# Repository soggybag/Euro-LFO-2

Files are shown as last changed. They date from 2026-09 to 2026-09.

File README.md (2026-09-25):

# Euro-LFO-2

Claude Conversation about the LFO Math

Here's the whole thing in one place, cleaned up.

## The circuit

```
        R6 10K        SHAPE 500K        D1/D2         RATE 100K
U1B(-) ──/\/\──── wiper ──/\/\──┬──── steering ────── wiper
  │                             │      diodes           │  pin1 = square (U1A out)
 C1 47n (to U1B out)                                     │  pin3 = GND via R4 4K7
                                                    
U1B: integrator   (+in = GND, C1 from out→in, out = triangle)
U1A: Schmitt trig  (-in = GND, +in from R1 150K [own out] and R5 100K [triangle])
     out = square, ±V_sat
```

## Step 1 — Schmitt thresholds set the triangle amplitude

U1A's + input, no current into the pin:

```
V+ = (V_tri·R1 + V_sq·R5) / (R1 + R5)
```

Trips when `V+ = 0`:

```
V_tri,trip = −V_sq · (R5/R1)
```

So the triangle bounces between `±V_sat·(R5/R1)`, giving a peak-to-peak swing:

```
ΔV_pp = 2·V_sat·(R5/R1) = 2·V_sat·(100K/150K) = 1.33·V_sat  ≈ 14 V pp  (±7 V)
```

## Step 2 — Integrator ramp rate

Summing node is a virtual ground, so the timing current is set entirely by the drive voltage and the series resistance:

```
slope = |dV_tri/dt| = V_drive / (R_t · C1)
```

`V_drive` = RATE wiper voltage minus one diode drop; `R_t` = series resistance for that half-cycle.

## Step 3 — Period

Each ramp traverses the **full** pp swing, and the two halves use the two halves of SHAPE (`R_a + R_b = 500K`) with R6 and the RATE source resistance `R_th` in both:

```
T = t_up + t_down
  = 2·(R5/R1)·(V_sat/V_drive)·C1·[ (R6 + R_a + R_th) + (R6 + R_b + R_th) ]
```

```
┌────────────────────────────────────────────────────────────────┐
│  T = 2·(R5/R1)·C1·( 2·R6 + R_SHAPE + 2·R_th ) · V_sat/(V_th−V_f) │
└────────────────────────────────────────────────────────────────┘
```

Key point: **R6 and R_th count twice** (in the path on both ramps); **SHAPE counts once** (the wiper splits it, halves sum to 500 K). That's why SHAPE changes symmetry/PWM but not frequency.

## Idealized form (RATE max, ignore diode)

`V_th → V_sat`, `R_th → 0`, and **V_sat cancels**:

```
        R1                    1
f  ≈  ────── · ──────────────────────────────
        R5       2 · C1 · (2·R6 + R_SHAPE)
```

## Numbers

```
R1/R5 = 1.5
2·C1·(2·R6 + R_SHAPE) = 2·(47 nF)·(20K + 500K) = 0.0489

f_max ≈ 1.5 / 0.0489 ≈ 31 Hz     (T ≈ 33 ms)
```

As RATE turns down, `V_th` falls and stretches the period:

| RATE wiper | V_th | f (approx) |
|---|---|---|
| full up | V_sat | ~30 Hz |
| middle | ~0.5·V_sat | ~14 Hz |
| near bottom | ~0.045·V_sat ≈ 0.47 V | crawls / stalls (below the ~0.5 V diode drop) |

**Practical range ≈ 0.3 Hz to ~30 Hz.**

## Notes

- **V_sat** ≈ ±10.5 V (TL074 stops ~1.5 V short of the rails). It drops out of the ideal formula — bigger swing = taller triangle *and* faster ramp, cancels.
- **Op-amp is now an LM324DT** (JLCPCB basic part C71035, pin-compatible with the TL074). Its swing is asymmetric — about +10.5 V but down to within a few hundred mV of −12 V — so the Schmitt thresholds are uneven: expect a ~0.5 V DC offset on the triangle and SHAPE's 50 % point shifted slightly off centre. Its ~0.4 V/µs slew gives ~50 µs square-wave edges, irrelevant at LFO rates. A TL074 still drops straight in if you want the symmetric JFET behaviour.
- Comparator propagation delay with the LM324 is a few µs vs a 33 ms period → still negligible.
- **V_f** ≈ 0.4–0.5 V steering-diode drop. It does *not* scale with V_sat, so it's what makes the low end nonlinear and adds mild temp drift (−2 mV/°C).
- **To lower the whole range**, scale **C1** up (470 n → ~0.1–3 Hz; 1 µF → ~1.4 Hz max). Don't retune with R5/R1 — that moves amplitude and frequency together.
- **C1 dielectric:** X7R drifts a few % — fine for an LFO. C0G only if you want the rate rock-stable.

Close, but the RATE knob isn't a series resistance you can add — it's a **voltage divider** on the drive (square wave → wiper → GND through R4). So it *multiplies* the rate rather than adding to the timing resistance.

## Ballpark model

**Fast end (RATE maxed)** — the idealized formula as-is:

```
        R1                1                1.5
f_max ≈ ── · ───────────────────────── ≈ ───────────── ≈ 30 Hz
        R5    2·C1·(2·R6 + R_SHAPE)      2·47n·520K
```

**Anywhere else** — scale by the knob:

```
f ≈ f_max · (V_th / V_sat) ≈ f_max · (fraction of knob rotation)
```

roughly linear for a linear-taper pot.

**Slow end (RATE at minimum)** — the drive collapses to the R4 divider:

```
                R4              4.7K
f_min ≈ f_max · ────────── ≈ 30·────── ≈ 1.4 Hz
                R_RATE+R4        104.7K
```

and the ~0.45 V diode drop eats the last sliver, so it actually **stalls at the end stop** — call the usable floor ~1 Hz.

## So

**~1 Hz to ~30 Hz, ~15 Hz at noon.**

## Why "+100K after R_SHAPE" doesn't give the min

The RATE pot's *resistance* contribution (its Thévenin source R looking back into the wiper) only swings from 0 to about **25K** — parallel combination of its two halves — and even at max that changes `f` by ~5%. The 20:1 rate span is entirely the *voltage* division, which is a multiplier, not a term you add to the ohms.

If you want the classic slow-LFO window, scale **C1**: 470 n → ~0.1–3 Hz, 1 µF → ~0.05–1.4 Hz.

It depends on what you want it to modulate, but here are the anchor points:

| Use | Rate | Period |
|---|---|---|
| Slow evolving pad / drone movement | 0.01–0.1 Hz | 10–100 s |
| Once per bar (120 BPM, 4/4) | 0.5 Hz | 2 s |
| Once per beat (120 BPM) | 2 Hz | 0.5 s |
| Rhythmic "wobble" | 1–8 Hz | — |
| Vibrato / tremolo | 4–8 Hz | — |
| Buzzy / edge-of-audio modulation | 20–30 Hz | — |
| Audio-rate (through-zero FM, AM, LFO-as-oscillator) | 30 Hz–2 kHz | — |

## The all-rounder target

A standalone modulation LFO wants roughly **0.05 Hz (≈20 s) to ~20 Hz** — that covers "slow filter sweep" up through "vibrato." The catch is that's a ~400:1 span, and a single knob over that range feels terrible with a linear taper (everything useful is crammed into the last few degrees). So real LFOs do one of:

- **Tapered pot** — reverse-log / "C" taper on RATE so the slow-to-medium zone gets most of the rotation.
- **Range switch** — a 2- or 3-position switch that swaps the timing cap, e.g. slow / med / fast.
- Both.

Extending the top past ~30 Hz into audio rate is a nice bonus but a separate design goal — this TL074 + diode-shaper topology isn't built for clean audio-rate output, so I'd not chase it here.

## For your circuit

Your span ratio is locked at about `(R_RATE + R4)/R4 ≈ 22:1` by the RATE divider. C1 just slides that 22:1 window up or down:

| C1 | Range | Character |
|---|---|---|
| 47 nF (now) | ~1.4–30 Hz | fast LFO — no slow sweeps |
| **100 nF** | **~0.7–14 Hz** | good general-purpose single range |
| 220 nF | ~0.3–6 Hz | slow/medium |
| 1 µF | ~0.06–1.4 Hz | slow-only |

My suggestion: **C1 = 100 nF** for a better single-range LFO, plus a **SPDT range switch** paralleling a larger cap (say +2.2 µF) to drop into a slow mode (~0.03–0.6 Hz) when you want it. And swap RATE to a reverse-log pot.

Don't try to widen the 22:1 span much by shrinking R4 — the steering diodes need the wiper voltage to stay above ~1 V to keep oscillating, so the bottom of the knob just goes mushy and stalls rather than getting genuinely slow. Sliding the window with C1 (or switching it) is the reliable lever.

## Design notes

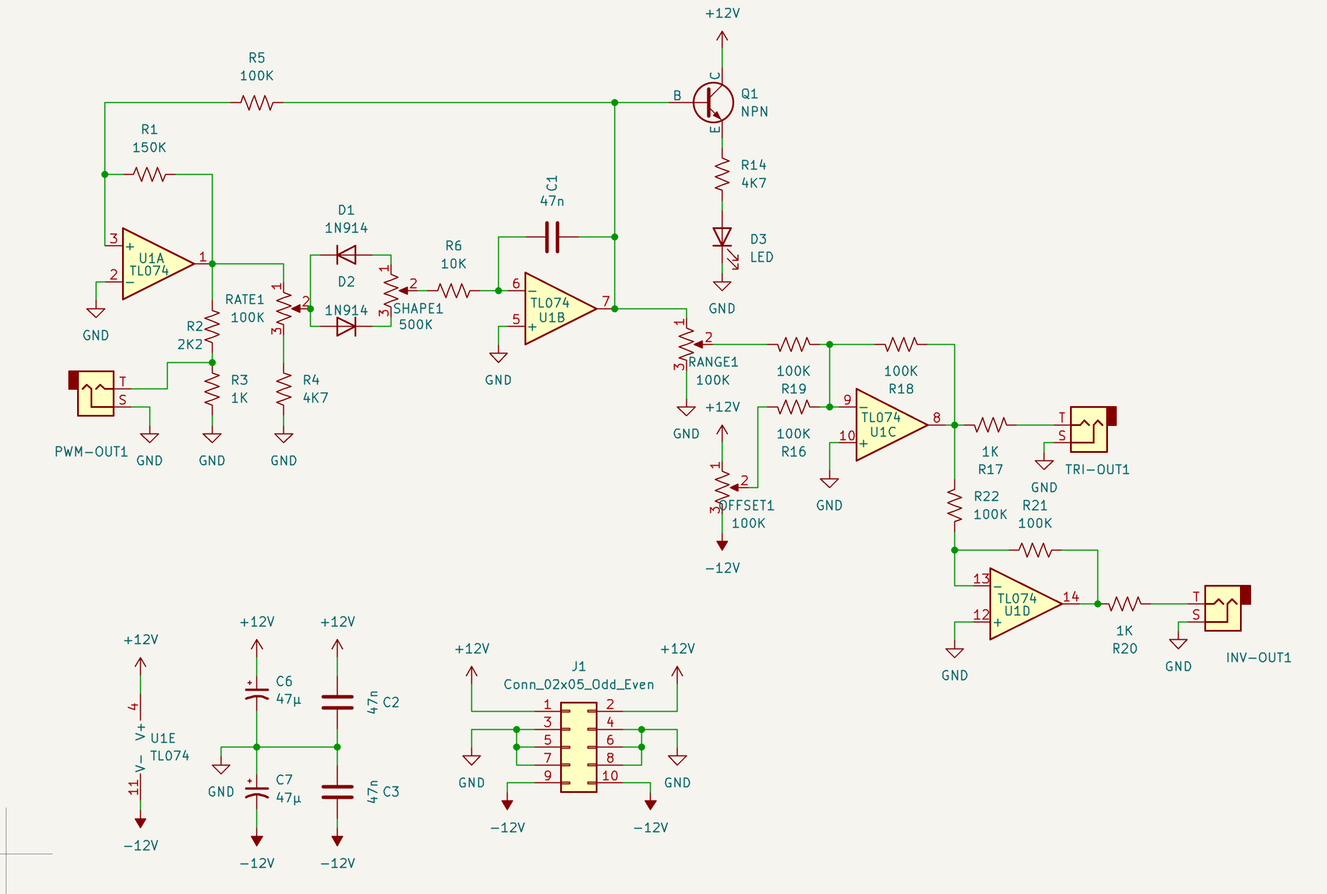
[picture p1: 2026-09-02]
Screenshot 2026-08-28 at 5.44.02 PM.png

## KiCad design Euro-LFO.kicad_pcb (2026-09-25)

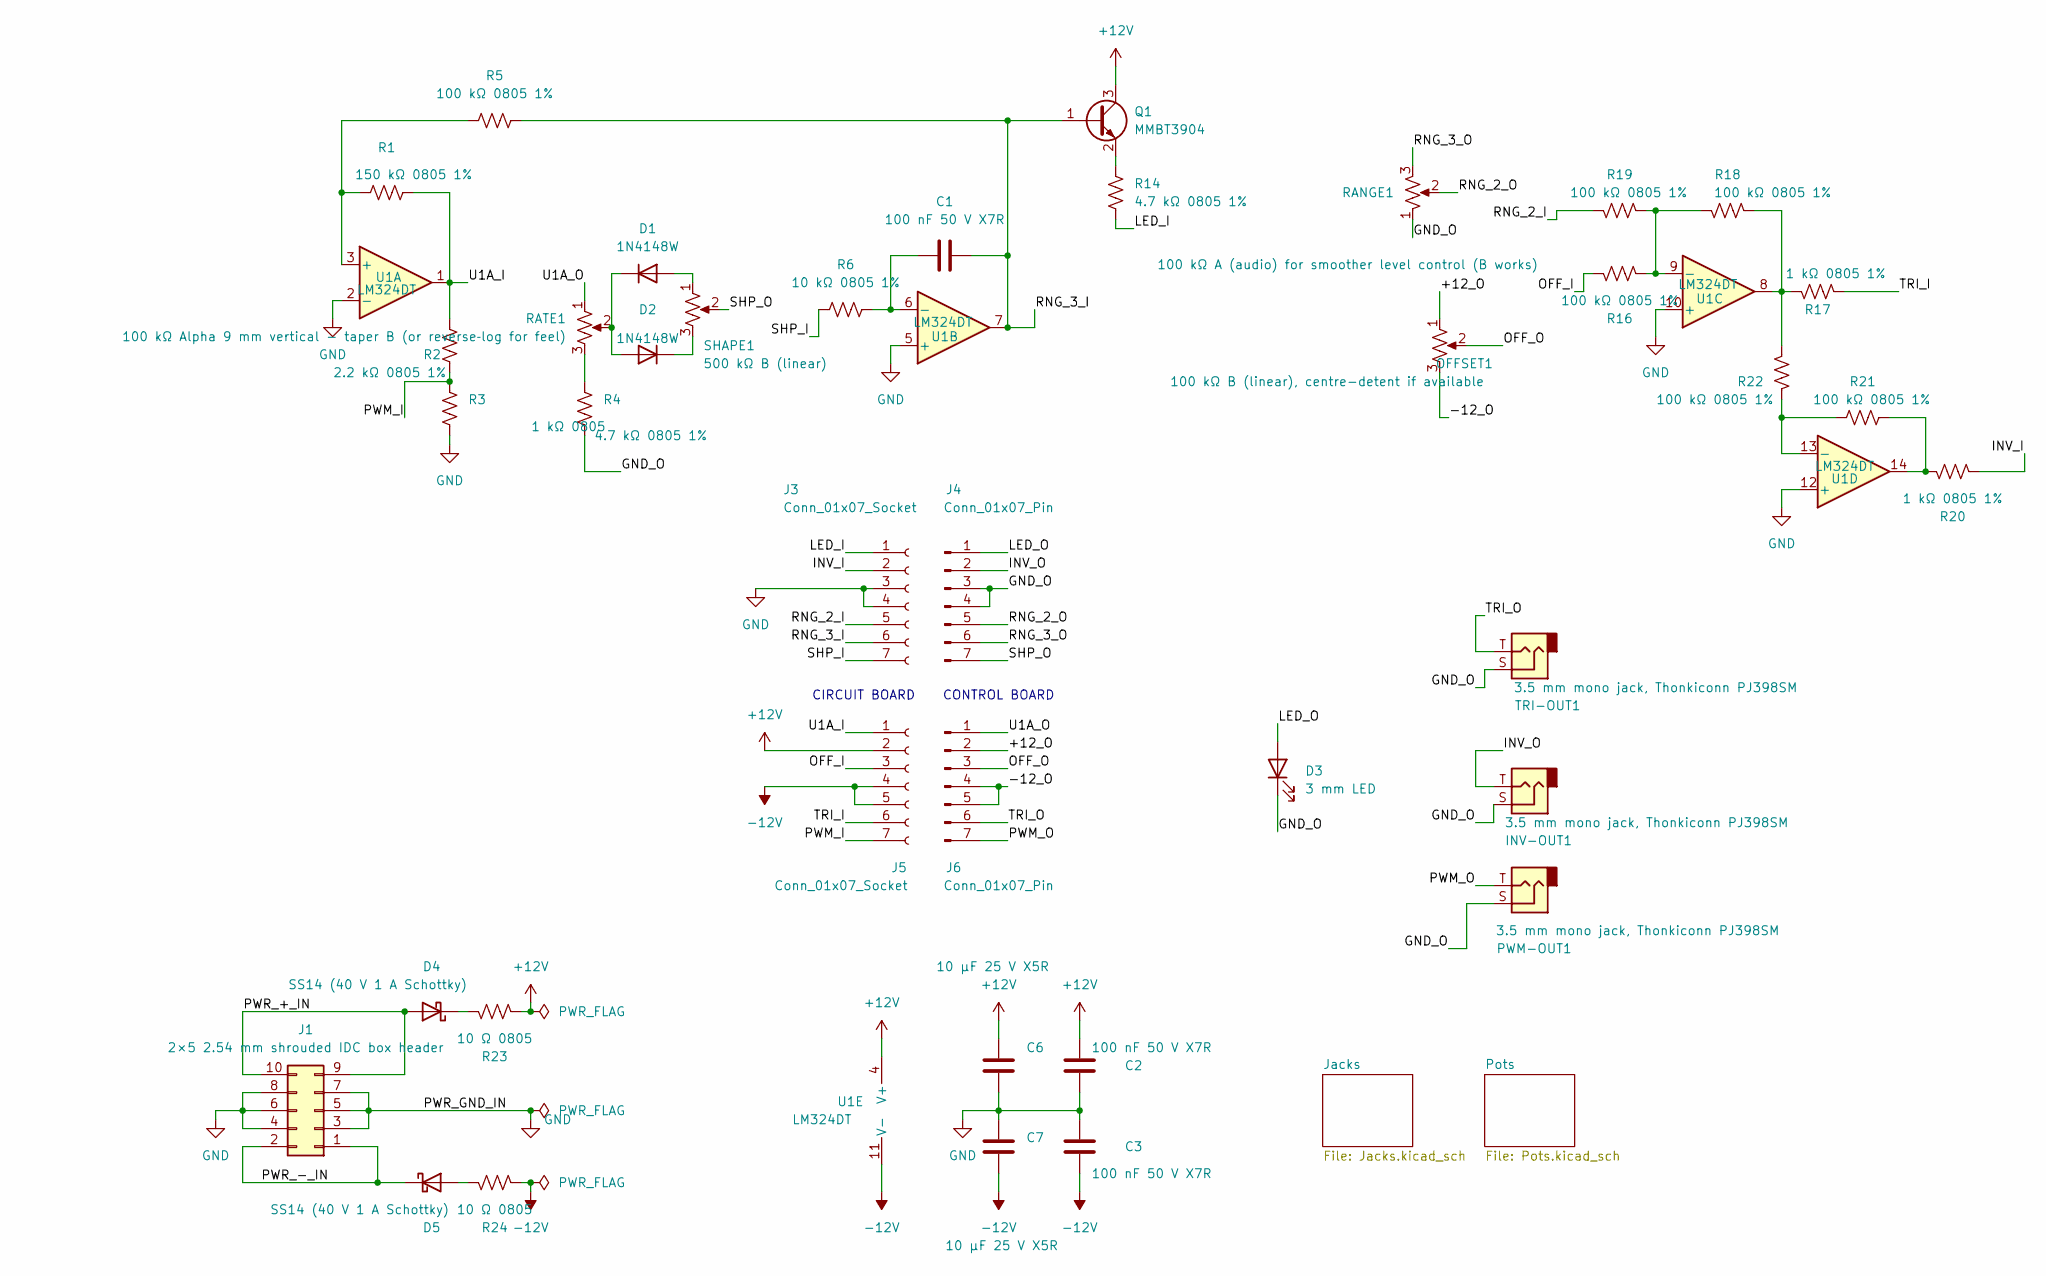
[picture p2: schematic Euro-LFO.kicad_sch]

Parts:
C1, C2, C3: 100 nF 50 V X7R; C_0805_2012Metric; LCSC C49678
C6, C7: 10 µF 25 V X5R; C_0805_2012Metric; LCSC C15850
D1, D2: 1N4148W; D_SOD-123; LCSC C81598
D3: 3 mm LED; LED_D3.0mm
D4, D5: SS14 (40 V 1 A Schottky); D_SMA; LCSC C2480
INV-OUT1: 3.5 mm mono jack, Thonkiconn PJ398SM; Jack_3.5mm_QingPu_WQP-PJ398SM_Vertical_CircularHoles
J1: 2×5 2.54 mm shrouded IDC box header; IDC-Header_2x05_P2.54mm_Vertical
J3, J5: Conn_01x07_Socket; PinSocket_1x07_P2.54mm_Vertical
J4, J6: Conn_01x07_Pin; PinHeader_1x07_P2.54mm_Vertical
OFFSET1: 100 kΩ B (linear), centre-detent if available; Potentiometer_Alpha_RD901F-40-00D_Single_Vertical
PWM-OUT1: 3.5 mm mono jack, Thonkiconn PJ398SM; Jack_3.5mm_QingPu_WQP-PJ398SM_Vertical_CircularHoles
Q1: MMBT3904; SOT-23; LCSC C20526
R1: 150 kΩ 0805 1%; R_0805_2012Metric; LCSC C17470
R2: 2.2 kΩ 0805 1%; R_0805_2012Metric; LCSC C17520
R3: 1 kΩ 0805; R_0805_2012Metric; LCSC C17513
R4, R14: 4.7 kΩ 0805 1%; R_0805_2012Metric; LCSC C17673
R5, R16, R18, R19, R21, R22: 100 kΩ 0805 1%; R_0805_2012Metric; LCSC C149504
R6: 10 kΩ 0805 1%; R_0805_2012Metric; LCSC C17414
R17, R20: 1 kΩ 0805 1%; R_0805_2012Metric; LCSC C17513
R23, R24: 10 Ω 0805; R_0805_2012Metric; LCSC C17415
RANGE1: 100 kΩ A (audio) for smoother level control (B wo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; Potentiometer_Alpha_RD901F-40-00D_Single_Vertical
RATE1: 100 kΩ Alpha 9 mm vertical - taper B (or reverse‑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; Potentiometer_Alpha_RD901F-40-00D_Single_Vertical
SHAPE1: 500 kΩ B (linear); Potentiometer_Alpha_RD901F-40-00D_Single_Vertical
TRI-OUT1: 3.5 mm mono jack, Thonkiconn PJ398SM; Jack_3.5mm_QingPu_WQP-PJ398SM_Vertical_CircularHoles
U1: LM324DT; SO-14_3.9x8.65mm_P1.27mm; LCSC C71035

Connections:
+12V: C2.1, C6.1, J5.2, Q1.3 (C), R23.1, U1.4 (V+)
-12V: C3.2, C7.2, J5.4, J5.5, R24.1, U1.11 (V-)
/+12_O: J6.2, OFFSET1.1
/-12_O: J6.4, J6.5, OFFSET1.3
/GND_O: D3.1 (K), INV-OUT1.S, J4.3, J4.4, PWM-OUT1.S, R4.1, RANGE1.1, TRI-OUT1.S
/INV_I: J3.2, R20.1
/INV_O: INV-OUT1.T, J4.2
/LED_I: J3.1, R14.2
/LED_O: D3.2 (A), J4.1
/OFF_I: J5.3, R16.2
/OFF_O: J6.3, OFFSET1.2
/PWM_I: J5.7, R2.1, R3.2
/PWM_O: J6.7, PWM-OUT1.T
/PWR_+_IN: D4.2 (A), J1.9, J1.10
/PWR_-_IN: D5.1 (K), J1.1, J1.2
/RNG_2_I: J3.5, R19.2
/RNG_2_O: J4.5, RANGE1.2
/RNG_3_I: C1.2, J3.6, Q1.1 (B), R5.1, U1.7
/RNG_3_O: J4.6, RANGE1.3
/SHP_I: J3.7, R6.2
/SHP_O: J4.7, SHAPE1.2
/TRI_I: J5.6, R17.1
/TRI_O: J6.6, TRI-OUT1.T
/U1A_I: J5.1, R1.2, R2.2, U1.1
/U1A_O: J6.1, RATE1.1
GND: C2.2, C3.1, C6.2, C7.1, J1.3, J1.4, J1.5, J1.6, J1.7, J1.8, J3.3, J3.4, R3.1, U1.2 (-), U1.5 (+), U1.10 (+), U1.12 (+)
unnamed: D1.2 (A), SHAPE1.1
unnamed: D1.1 (K), D2.2 (A), RATE1.2
unnamed: D2.1 (K), SHAPE1.3
unnamed: D4.1 (K), R23.2
unnamed: D5.2 (A), R24.2
unnamed: Q1.2 (E), R14.1
unnamed: R4.2, RATE1.3
unnamed: R17.2, R18.1, R22.1, U1.8
unnamed: R20.2, R21.1, U1.14
unnamed: R1.1, R5.2, U1.3 (+)
unnamed: C1.1, R6.1, U1.6 (-)
unnamed: R16.1, R18.2, R19.1, U1.9 (-)
unnamed: R21.2, R22.2, U1.13 (-)

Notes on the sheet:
CONTROL BOARD
CIRCUIT BOARD

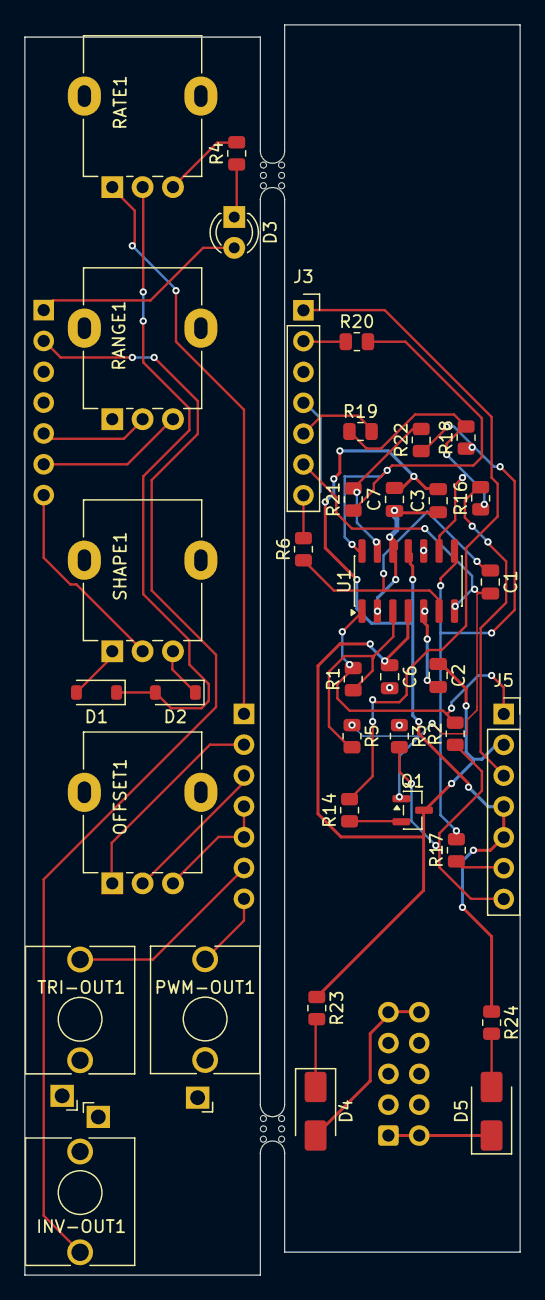
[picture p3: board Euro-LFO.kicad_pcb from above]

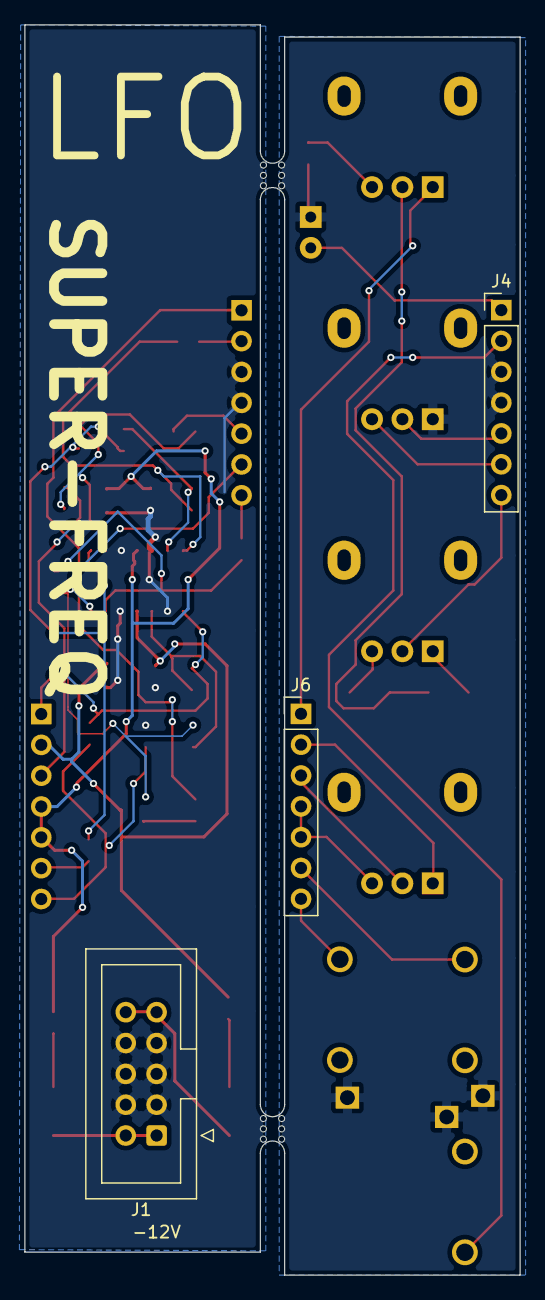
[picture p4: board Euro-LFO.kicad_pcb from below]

Board: 2 copper layers, 40.8 x 103.0 mm, 40 parts (3 on the bottom side), 39 nets.

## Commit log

2026-09-02 added schematic
2026-09-15 added pin headers
    [Euro-LFO.kicad_pcb, Euro-LFO.kicad_sch, Jacks.kicad_sch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]
2026-09-16 work in progress
    [Euro-LFO.kicad_pcb, Euro-LFO.kicad_sch, untitled.kicad_sch]
2026-09-16 Sorting out cross board connections
    [Euro-LFO.kicad_pcb, Euro-LFO.kicad_sch]
2026-09-16 flipped parts
    Flipped parts, cleaned up edge cuts, untangled rats nest.
    [Euro-LFO.kicad_sch]
2026-09-18 added mousebites
    [Euro-LFO.kicad_pcb, Euro-LFO.kicad_sch]
2026-09-18 V1 complete
    Needs review!
    [Euro-LFO.kicad_pcb]
2026-09-25 separated front panel
    [Euro-LFO-B_Cu.gbl, Euro-LFO-B_Mask.gbs, Euro-LFO-B_Paste.gbp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]
2026-09-25 review and update
    Reviewed ad updated board dimensions and outlines. Checked position of jacks and pots.
    [Euro-LFO.kicad_pcb, Front-Panel.kicad_pcb]
